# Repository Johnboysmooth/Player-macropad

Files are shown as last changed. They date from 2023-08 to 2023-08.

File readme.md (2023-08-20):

# Player! V1.31

Player! is a five button macropad originally designed to accomodate changing music settings in Spotify without tabbing into the Spotify client. By default it is programmed to use dedicated media keys, which can be further optimised with global hotkeys using [Toastify](https://github.com/aleab/toastify) or [Volumey](https://apps.microsoft.com/store/detail/volumey/9MZCQ03MX0S3?hl=en-gb&gl=gb&rtc=1).

Using four cherry compatible switches, Player! provides dedicated keys for pausing/playing music -  returning to a previous song, and skipping to the next song. The fourth switch remains user programmable, binded to 'insert' by default to be used as dedicated Discord mute key. A rotary encoder allows for volume control, with a toggle function bound to its embedded switch to allow rotary control of rewinding and fast-forwarding music. Player! is entirely customisable, using [Vial](https://get.vial.today/) for rebinding keys.

V1.31 has made the Player! bigger to accommodate 4 mounting holes, which will be used to mount the PCB to a case. The otherwise empty space is covered in a tropical leaf pattern on the top copper layer; a number of changes have been made to improve the appearance and the fit/function of the base.

# Images
Assembled on Base:
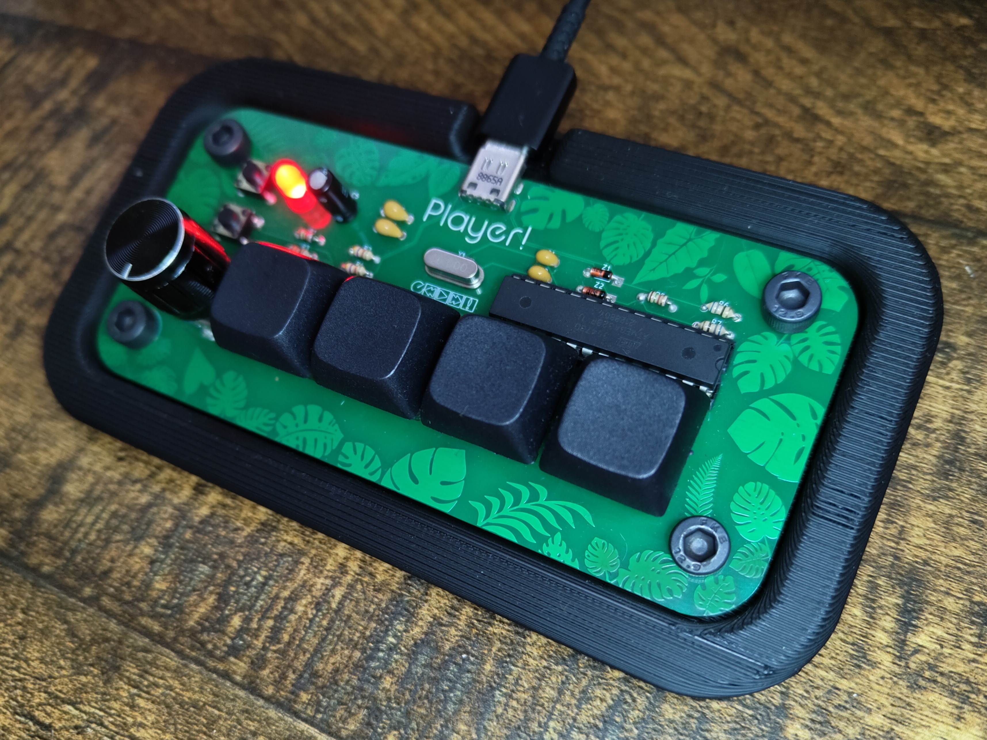
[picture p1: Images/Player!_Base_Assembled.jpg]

Assembled PCB:
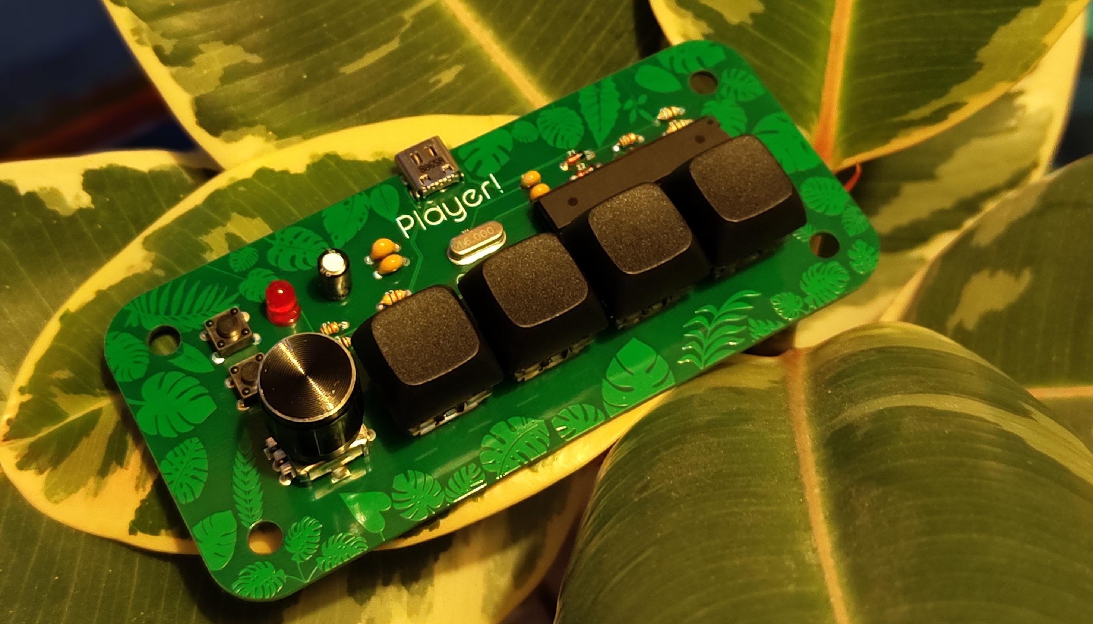
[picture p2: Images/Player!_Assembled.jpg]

3D Model in KiCAD:
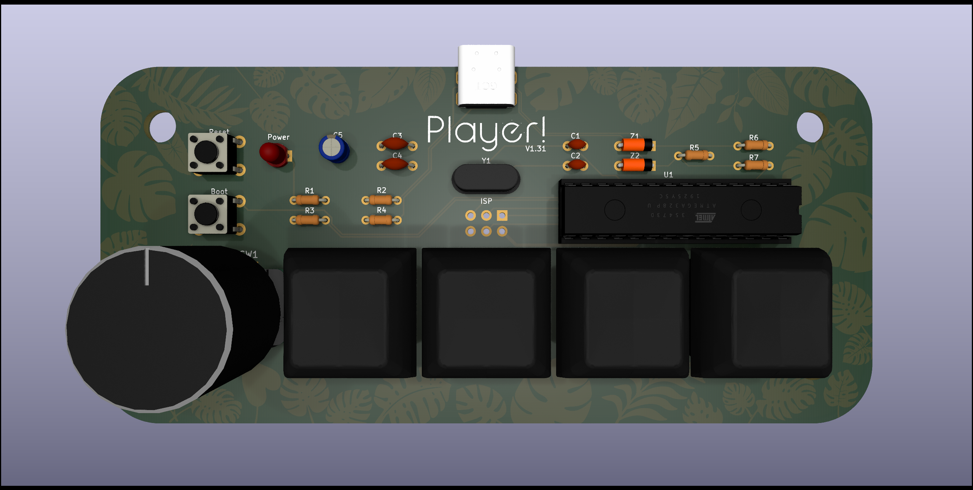
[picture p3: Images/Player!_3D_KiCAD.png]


# Documentation

Build information can be found in this [document](/Player!_Info.pdf), covering topics such as the Bill of Materials and Flashing information.

## License
<br />Player! is licensed under a <a rel="license" href="http://creativecommons.org/licenses/by-nc/4.0/">Creative Commons Attribution-NonCommercial 4.0 International License </a>

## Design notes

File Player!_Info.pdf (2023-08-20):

## Hardware

Bill of Materials
The bill of materials is hosted on Octopart, available here. (https://octopart.com/bom-tool/iGNVRgwb) Almost all the components are generic and as a result can be sourced from any good electronic supplier. The only real exceptions are the USB-C connector and the ATMega328 for which there are no alternatives (as far as I know).
Base/Case
Player! is currently housed in a 3D printed black PLA base, which holds the Player! PCB facing forwards at 10°. The base uses M5x10mm brass threaded inserts to accept M5x10mm hex head screws. The self-tapping brass inserts used to prevent damage caused by screwing/unscrewing the hex head screws directly into the base.

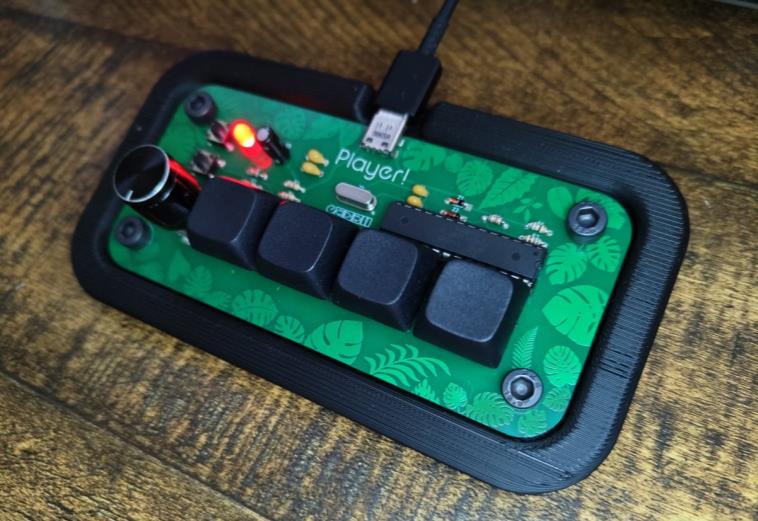
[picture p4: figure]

Whilst testing the sizing for the brass threaded inserts, I found small PLA standoffs to be quite an elegant solution, leaving the PCB “floating” ... however, these can be tricky to align at an angle.

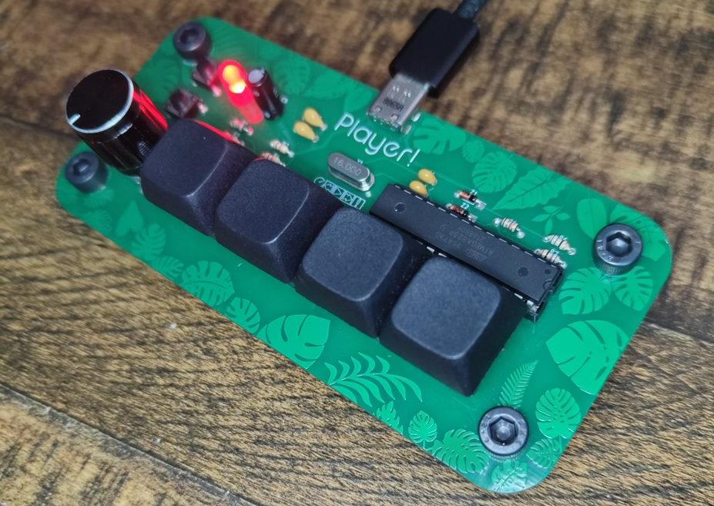
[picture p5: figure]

The STL files to print your own base or angled standoffs can be found here. (https://github.com/Johnboysmooth/Player-macropad/tree/main/Base)

## Firmware - QMK

Entering Bootloader Mode
Player! needs to be put into bootloader mode to allow QMK to be flashed via a USB connection:
1. Press and hold “Boot” button
2. Tap “Reset” button
3. Release “Boot” button

USBaspLoader will show up in device manager or as a connected device in QMK toolbox when the device has successfully entered bootloader mode, like so:

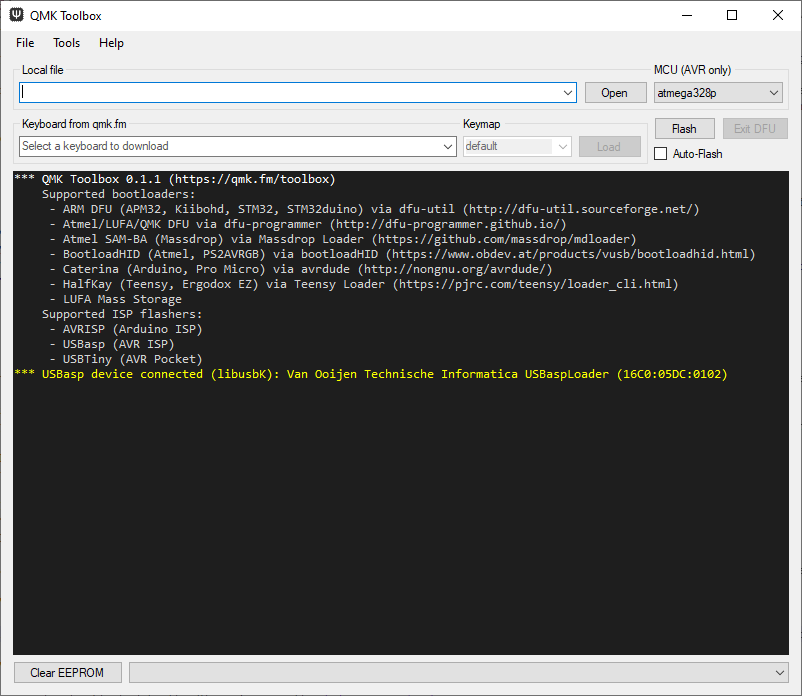
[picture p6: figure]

Flashing Firmware
Once Player! has been successfully put into bootloader mode, the firmware can be flashed. Download the player_vial.hex, (https://github.com/Johnboysmooth/Player-macropad/tree/main/Firmware) and point QMK toolbox to its location, and then click flash. Upon completion, press the “Reset” button on the Player! and it will be ready to use with the default keybinds.

## Firmware – Bootloader Information

The Player! Uses a USB bootloader that allows the ATMega328 to program itself with QMK, namely USBaspLoader. (https://www.fischl.de/usbasp/)

- My flavour of the bootloader is available here. (https://github.com/Johnboysmooth/USBaspLoader)
- The instructions for setting up the build environment can be found in the “readme”.
- Some changes will be required, such as changing the port or programmer definitions for your setup. These can be found on lines 9 and 44 of the makefile.inc respectively. Never edit the makefile directly.
- Flashing the ATMega328 once the build environment is setup:

“make flash” (flashes the makefile)

“make fuse” (sets fuses for the ATMega328)

## Rebinding Keys

Player! Supports the rebinding of keys using Vial. This can be done using the downloaded vial client, or simply navigating to vial.rocks in your web browser. When using the browser version, click “Start Vial” and select “johnboysmooth Player” from the pop up:

Vial should start and present the buttons and rotary knob of the Player!, which can then be rebound as required.

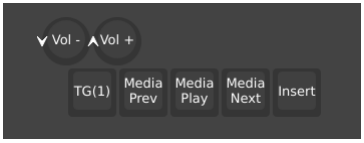
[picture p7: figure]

The two circles represent the rotary encoder, the directional arrows indicating the binds for clockwise/anti-clockwise rotation. TG(1) is for the rotary encoder switch, which by default toggles between the first and second layer. The remaining four buttons correspond to the four keyswitch buttons on the Player!.

## Future Work/Issues

Feedback is welcomed, including any issues which can be logged in the GitHub issues (https://github.com/Johnboysmooth/Player-macropad/issues) page. Player! continues to be developed, here are some future ideas:

- RGB backlighting.
- A case with transparent/translucent edges for LED shine through.
- Choc/Cherry switch compatibility, using footprints that support either switch.
- A “true” wireless device, supporting Bluetooth connectivity as well as Qi wireless charging to completely remove the need to ever connect via USB. This would have to include a small battery.

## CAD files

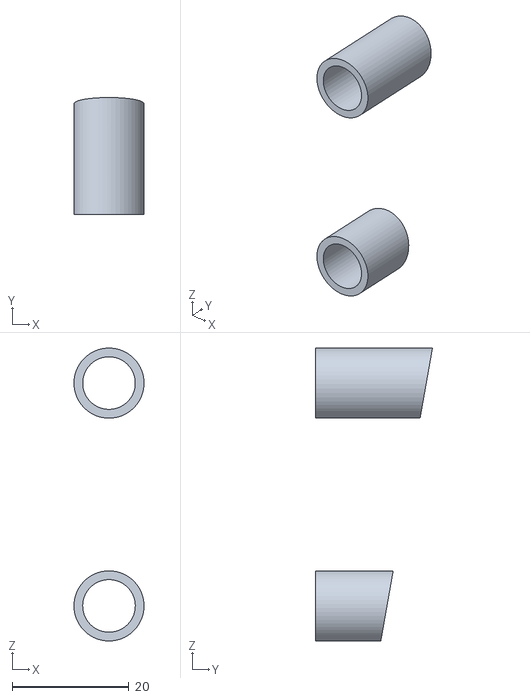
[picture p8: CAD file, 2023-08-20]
Base/Player!_Angled_Standoff.STL
12.0 x 20.0 x 50.1

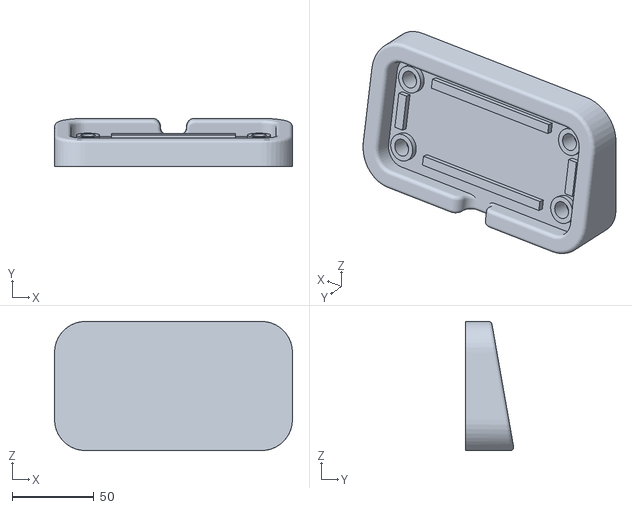
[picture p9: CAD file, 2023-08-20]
Base/Player!_Base.STL
145.8 x 29.6 x 79.2

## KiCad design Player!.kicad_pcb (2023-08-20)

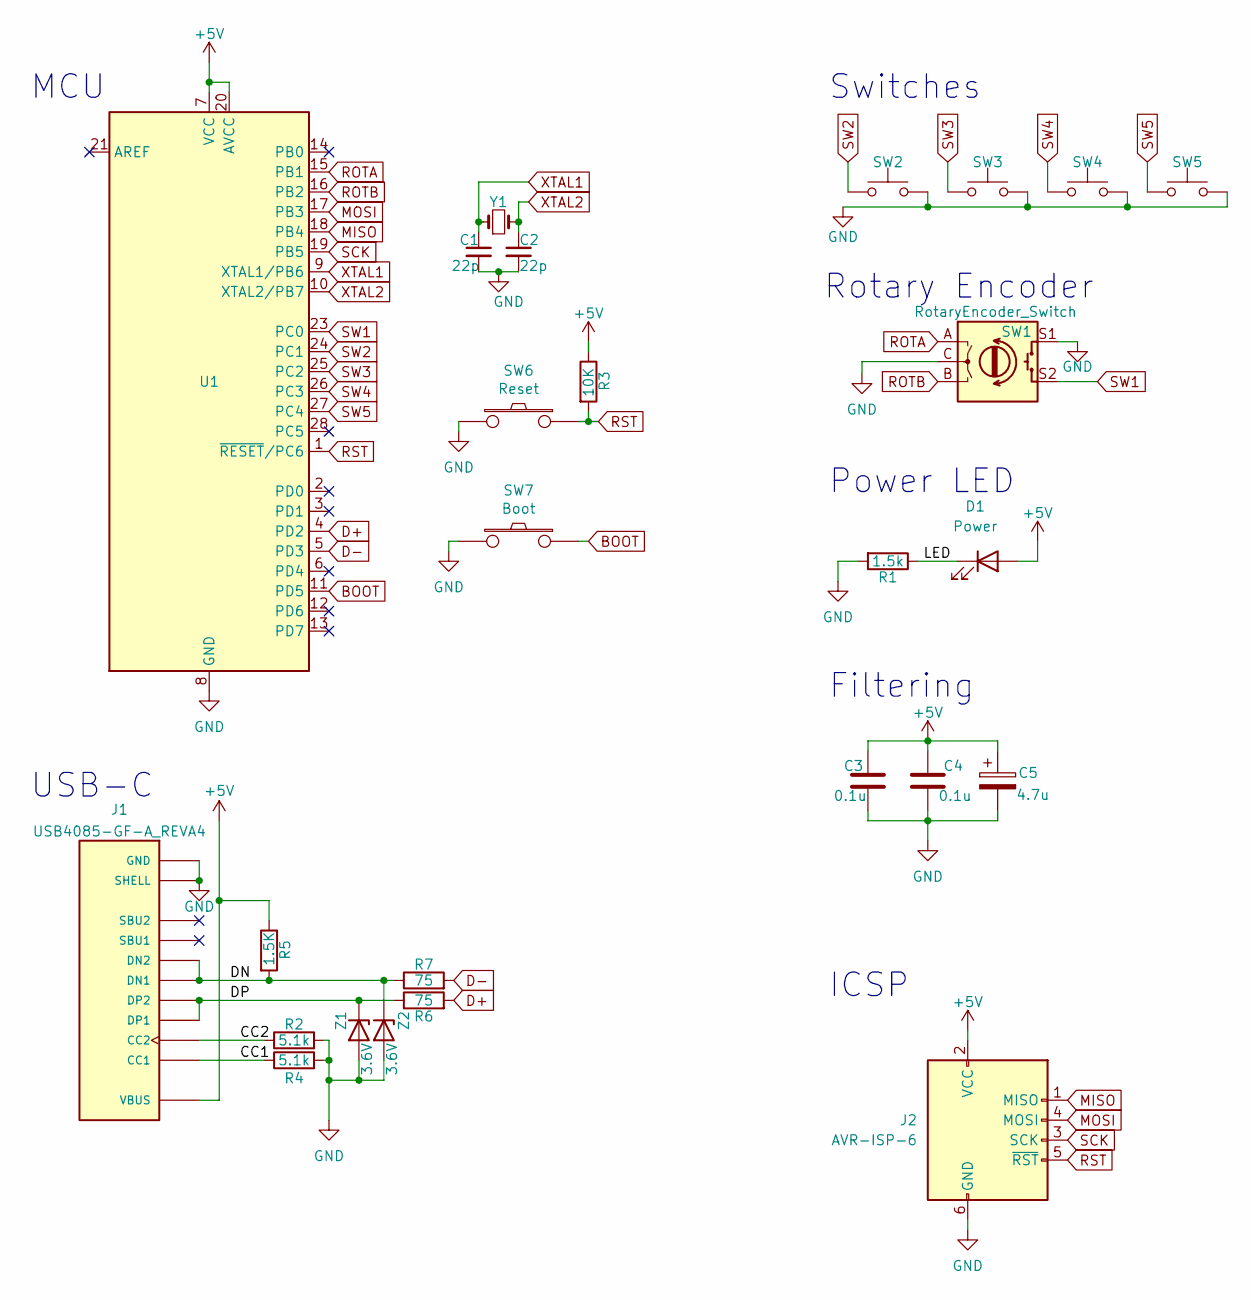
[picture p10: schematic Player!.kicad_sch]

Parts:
C1, C2: 22p; C_Disc_D3.0mm_W1.6mm_P2.50mm
C3, C4: 0.1u; C_Disc_D4.3mm_W1.9mm_P5.00mm
C5: 4.7u; CP_Radial_D4.0mm_P1.50mm
D1: Power; LED_D3.0mm
J1: USB4085-GF-A_REVA4; GCT_USB4085-GF-A_REVA4; PARTREV A4
J2: AVR-ISP-6; PinHeader_2x03_P2.54mm_Vertical
R1: 1.5k; R_Axial_DIN0204_L3.6mm_D1.6mm_P5.08mm_Horizontal
R2, R4: 5.1k; R_Axial_DIN0204_L3.6mm_D1.6mm_P5.08mm_Horizontal
R3: 10K; R_Axial_DIN0204_L3.6mm_D1.6mm_P5.08mm_Horizontal
R5: 1.5K; R_Axial_DIN0204_L3.6mm_D1.6mm_P5.08mm_Horizontal
R6, R7: 75; R_Axial_DIN0204_L3.6mm_D1.6mm_P5.08mm_Horizontal
SW1: RotaryEncoder_Switch; RotaryEncoder_Alps_EC12E-Switch_Vertical_H20mm
SW2, SW3, SW4, SW5: SW_Push; SW_Hotswap_Kailh_MX_1.00u
SW6: Reset; SW_PUSH_6mm
SW7: Boot; SW_PUSH_6mm
U1: ATmega328P-P; ATmega328p DIP-28
Y1: Crystal; Crystal_HC49-4H_Vertical
Z1, Z2: 3.6V; D_DO-35_SOD27_P5.08mm_Horizontal

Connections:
+5V: C3.1, C4.1, C5.1, D1.2 (A), J1.A4 (VBUS), J1.A9 (VBUS), J1.B4 (VBUS), J1.B9 (VBUS), J2.2 (VCC), R3.1, R5.1, U1.7 (VCC), U1.20 (AVCC)
/CC1: J1.A5 (CC1), R4.1
/CC2: J1.B5 (CC2), R2.1
/DN: J1.A7 (DN1), J1.B7 (DN2), R5.2, R7.1, Z2.1 (K)
/DP: J1.A6 (DP1), J1.B6 (DP2), R6.1, Z1.1 (K)
/LED: D1.1 (K), R1.1
BOOT: SW7.2, U1.11 (PD5)
D+: R6.2, U1.4 (PD2)
D-: R7.2, U1.5 (PD3)
GND: C1.2, C2.2, C3.2, C4.2, C5.2, J1.A1 (GND), J1.A12 (GND), J1.B1 (GND), J1.B12 (GND), J1.P1 (SHELL), J1.P2 (SHELL), J1.P3 (SHELL), J1.P4 (SHELL), J2.6 (GND), R1.2, R2.2, R4.2, SW1.C, SW1.S1, SW2.2, SW3.2, SW4.2, SW5.2, SW6.1, SW7.1, U1.8 (GND), U1.22 (GND), Z1.2 (A), Z2.2 (A)
MISO: J2.1 (MISO), U1.18 (PB4)
MOSI: J2.4 (MOSI), U1.17 (PB3)
ROTA: SW1.A, U1.15 (PB1)
ROTB: SW1.B, U1.16 (PB2)
RST: J2.5 (~RST), R3.2, SW6.2, U1.1 (~RESET/PC6)
SCK: J2.3 (SCK), U1.19 (PB5)
SW1: SW1.S2, U1.23 (PC0)
SW2: SW2.1, U1.24 (PC1)
SW3: SW3.1, U1.25 (PC2)
SW4: SW4.1, U1.26 (PC3)
SW5: SW5.1, U1.27 (PC4)
XTAL1: C1.1, U1.9 (XTAL1/PB6), Y1.1
XTAL2: C2.1, U1.10 (XTAL2/PB7), Y1.2

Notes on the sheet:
USB-C
Switches
Rotary Encoder
Power LED
MCU
Filtering
ICSP

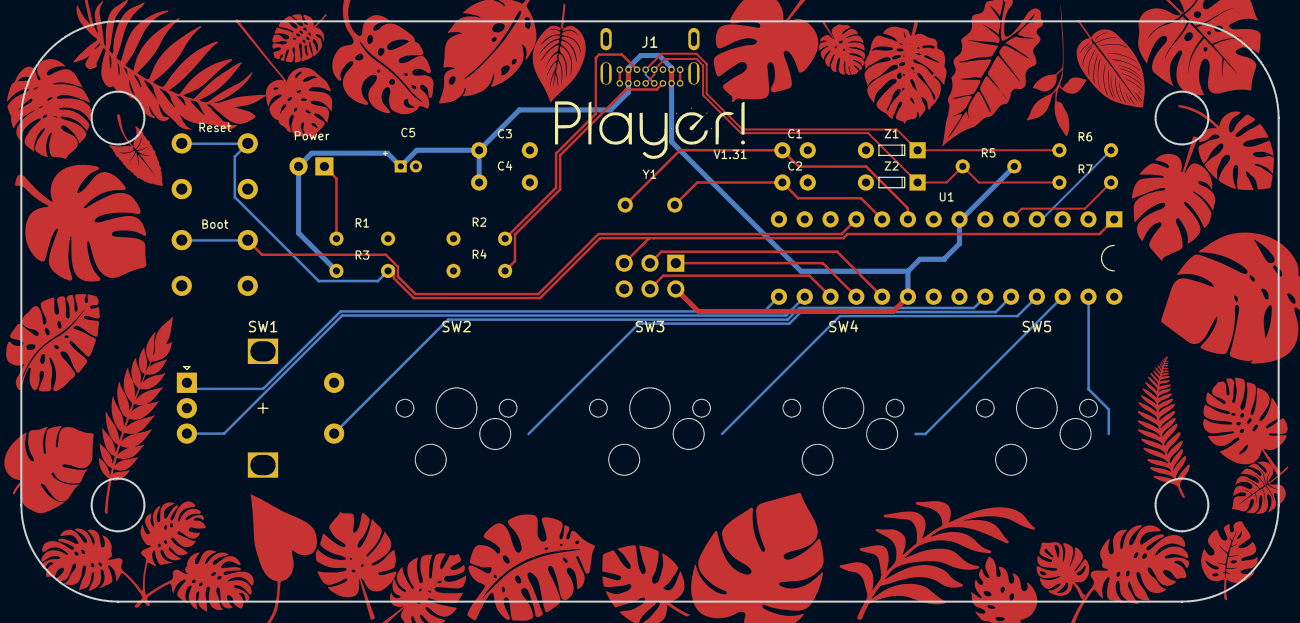
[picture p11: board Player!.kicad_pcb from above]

Board: 2 copper layers, 123.8 x 57.1 mm, 26 parts (0 on the bottom side), 23 nets.

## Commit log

2022-08-26 PCB & Libraries
    [Player!.kicad_pcb, Player!.kicad_sch]
2022-08-26 Case Model
    [Case.FCStd, Clear Top.FCStd]
2023-06-18 Updated to V1.31
    V1.31 makes the bigger to accommodate 4 mounting holes, adds a decorative tropical pattern to the top copper plane in the otherwise blank space; numerous small changes made to improve the overall app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
    [Case.FCStd, Clear Top.FCStd, Player!.kicad_pcb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]
2023-06-18 PCB changes
    Minor changes to correct D+ & D- tracks connecting
    [Player!.kicad_pcb]
2023-07-01 Final PCB changes for v1.31
    [Player!.kicad_pcb, Player!.kicad_sch]
2023-08-20 Updated silkscreen
2023-08-20 Added base
    Added 3d printable base as well as 3d printable standoffs.
    [Player!_Angled_Standoff.STL, Player!_Base.STL]
